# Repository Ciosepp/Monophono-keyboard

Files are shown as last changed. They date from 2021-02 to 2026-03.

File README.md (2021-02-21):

Mono Keyboard Analog Controller features

1-Monophonic pitch CV control
2-Gate CV control
3-Pitch bend wheel CV
4-Mod/expression wheel
5-Mod cv source selection
6-Two auxiliary CV controls
7-Midi out
8-Arpeggiator hold function
9-Arpeggiator latch function 
10-Arpeggiator time setting {60-300bpm}
11-Arpeggiator mode setting {up-down-up/down}
12-Arpeggiator ck source selection {int/ext}
13-Arpeggiator octave extension setting {1-2-3}Monophono-keyboard

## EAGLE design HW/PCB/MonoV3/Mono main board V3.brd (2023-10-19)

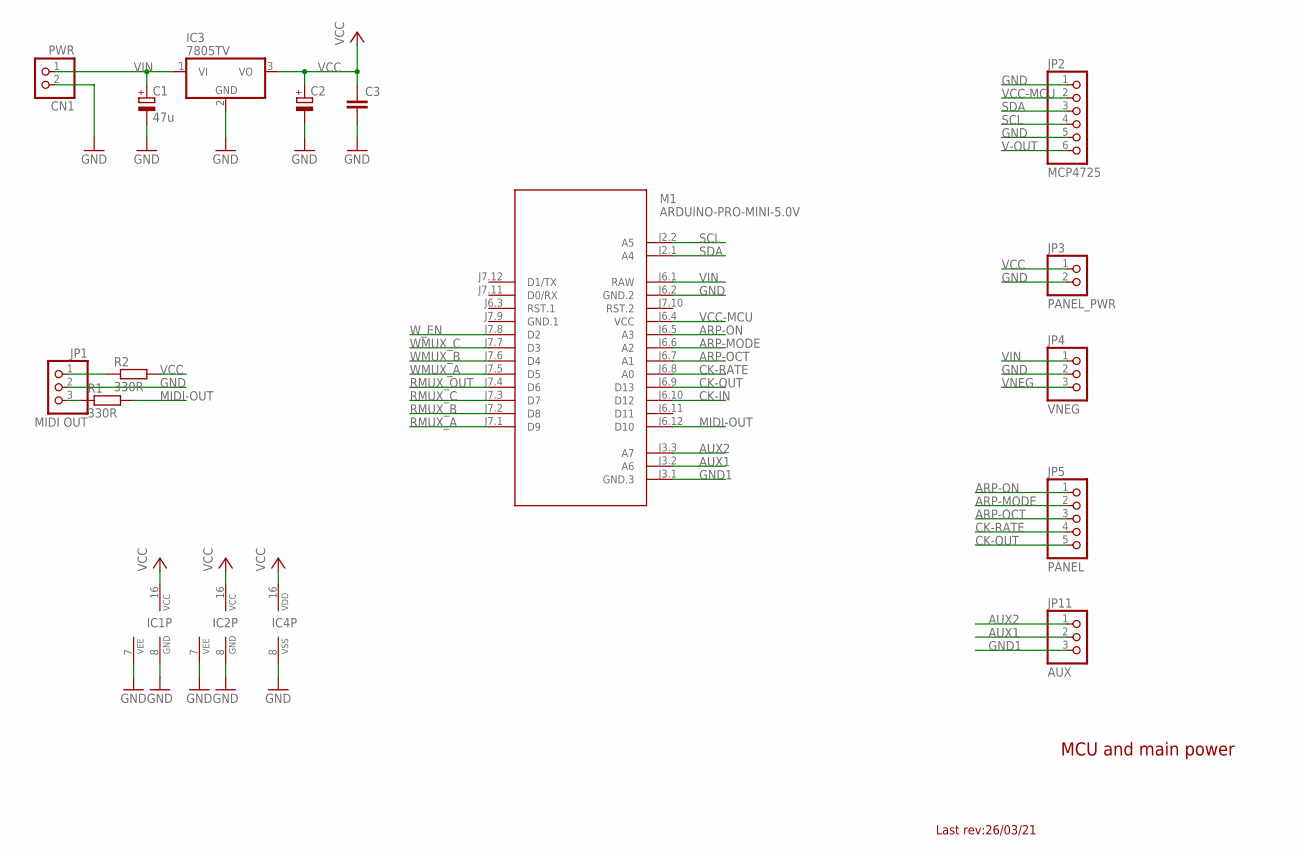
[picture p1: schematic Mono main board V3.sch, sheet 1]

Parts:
C1: 47u; E5-8,5
C2: CPOL-EUE5-8.5; E5-8,5
C3: C-EU050-025X075; C050-025X075
CN1: PWR; JST-PH-2-THM
IC1, IC2: 4051D; SO16
IC3: 7805TV; TO220V
IC4: 4040N; DIL16
JP1: MIDI OUT; 1X03
JP2: MCP4725; 1X06-CLEANBIG
JP3: PANEL_PWR; 1X02
JP4: VNEG; 1X03
JP5: PANEL; 1X05
JP11: AUX; 1X03
M1: ARDUINO-PRO-MINI-5.0V; ARDUINO-PRO-MINI#NP
R1, R2: 330R; R0805

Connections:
ARP-MODE: JP5.2, M1.J6.6 (A2)
ARP-OCT: JP5.3, M1.J6.7 (A1)
ARP-ON: JP5.1, M1.J6.5 (A3)
AUX1: JP11.2, M1.J3.2 (A6)
AUX2: JP11.1, M1.J3.3 (A7)
CK-IN: M1.J6.10 (D12); also elsewhere on the board
CK-OUT: JP5.5, M1.J6.9 (D13)
CK-RATE: JP5.4, M1.J6.8 (A0)
GND: C1.-, C2.-, C3.2, CN1.2 (1), IC1.7 (VEE), IC1.8 (GND), IC2.7 (VEE), IC2.8 (GND), IC3.2 (GND), IC4.8 (VSS), JP1.2, JP2.1, JP2.5, JP3.2, JP4.2, M1.J6.2 (GND.2); also elsewhere on the board
GND1: JP11.3, M1.J3.1 (GND.3)
GND.1: M1.J7.9 (GND.1)
MIDI-OUT: M1.J6.12 (D10), R1.2
unnamed: JP1.1, R2.1
unnamed: JP1.3, R1.1
RMUX_A: M1.J7.1 (D9); also elsewhere on the board
RMUX_B: M1.J7.2 (D8); also elsewhere on the board
RMUX_C: M1.J7.3 (D7); also elsewhere on the board
RMUX_OUT: M1.J7.4 (D6); also elsewhere on the board
SCL: JP2.4, M1.J2.2 (A5)
SDA: JP2.3, M1.J2.1 (A4)
V-OUT: JP2.6; also elsewhere on the board
VCC: C2.+, C3.1, IC1.16 (VCC), IC2.16 (VCC), IC3.3 (VO), IC4.16 (VDD), JP3.1, R2.2; also elsewhere on the board
VCC-MCU: JP2.2, M1.J6.4 (VCC)
VIN: C1.+, CN1.1 (2), IC3.1 (VI), JP4.1, M1.J6.1 (RAW); also elsewhere on the board
VNEG: JP4.3; also elsewhere on the board
WMUX_A: M1.J7.5 (D5); also elsewhere on the board
WMUX_B: M1.J7.6 (D4); also elsewhere on the board
WMUX_C: M1.J7.7 (D3); also elsewhere on the board
W_EN: M1.J7.8 (D2); also elsewhere on the board

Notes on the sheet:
MCU and main power
Last rev:26/03/21

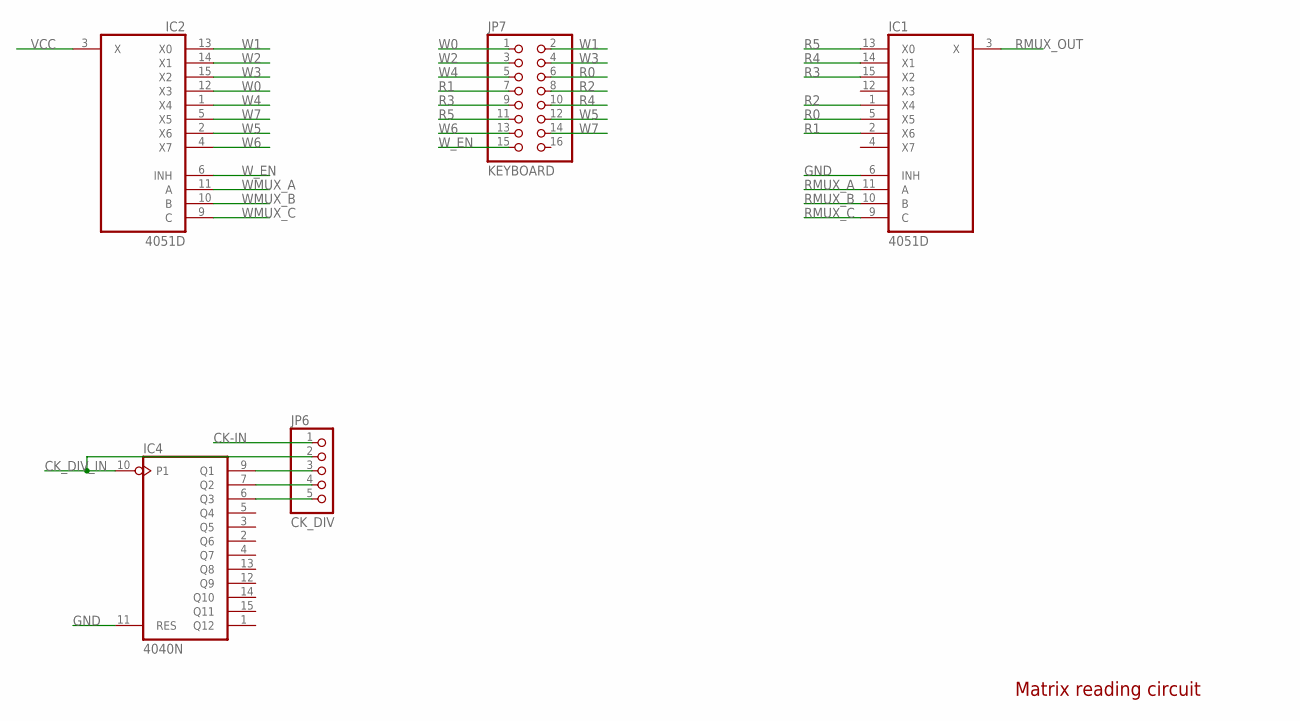
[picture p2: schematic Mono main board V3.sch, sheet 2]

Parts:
IC1, IC2: 4051D; SO16
IC4: 4040N; DIL16
JP6: CK_DIV; 1X05
JP7: KEYBOARD; 2X08

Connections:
CK-IN: JP6.1; also elsewhere on the board
CK_DIV_IN: IC4.10 (P1), JP6.2
GND: IC1.6 (INH), IC4.11 (RES); also elsewhere on the board
unnamed: IC4.9 (Q1), JP6.3
unnamed: IC4.7 (Q2), JP6.4
unnamed: IC4.6 (Q3), JP6.5
R0: IC1.5 (X5), JP7.6
R1: IC1.2 (X6), JP7.7
R2: IC1.1 (X4), JP7.8
R3: IC1.15 (X2), JP7.9
R4: IC1.14 (X1), JP7.10
R5: IC1.13 (X0), JP7.11
RMUX_A: IC1.11 (A); also elsewhere on the board
RMUX_B: IC1.10 (B); also elsewhere on the board
RMUX_C: IC1.9 (C); also elsewhere on the board
RMUX_OUT: IC1.3 (X); also elsewhere on the board
VCC: IC2.3 (X); also elsewhere on the board
W0: IC2.12 (X3), JP7.1
W1: IC2.13 (X0), JP7.2
W2: IC2.14 (X1), JP7.3
W3: IC2.15 (X2), JP7.4
W4: IC2.1 (X4), JP7.5
W5: IC2.2 (X6), JP7.12
W6: IC2.4 (X7), JP7.13
W7: IC2.5 (X5), JP7.14
WMUX_A: IC2.11 (A); also elsewhere on the board
WMUX_B: IC2.10 (B); also elsewhere on the board
WMUX_C: IC2.9 (C); also elsewhere on the board
W_EN: IC2.6 (INH), JP7.15; also elsewhere on the board

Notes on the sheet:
Matrix reading circuit

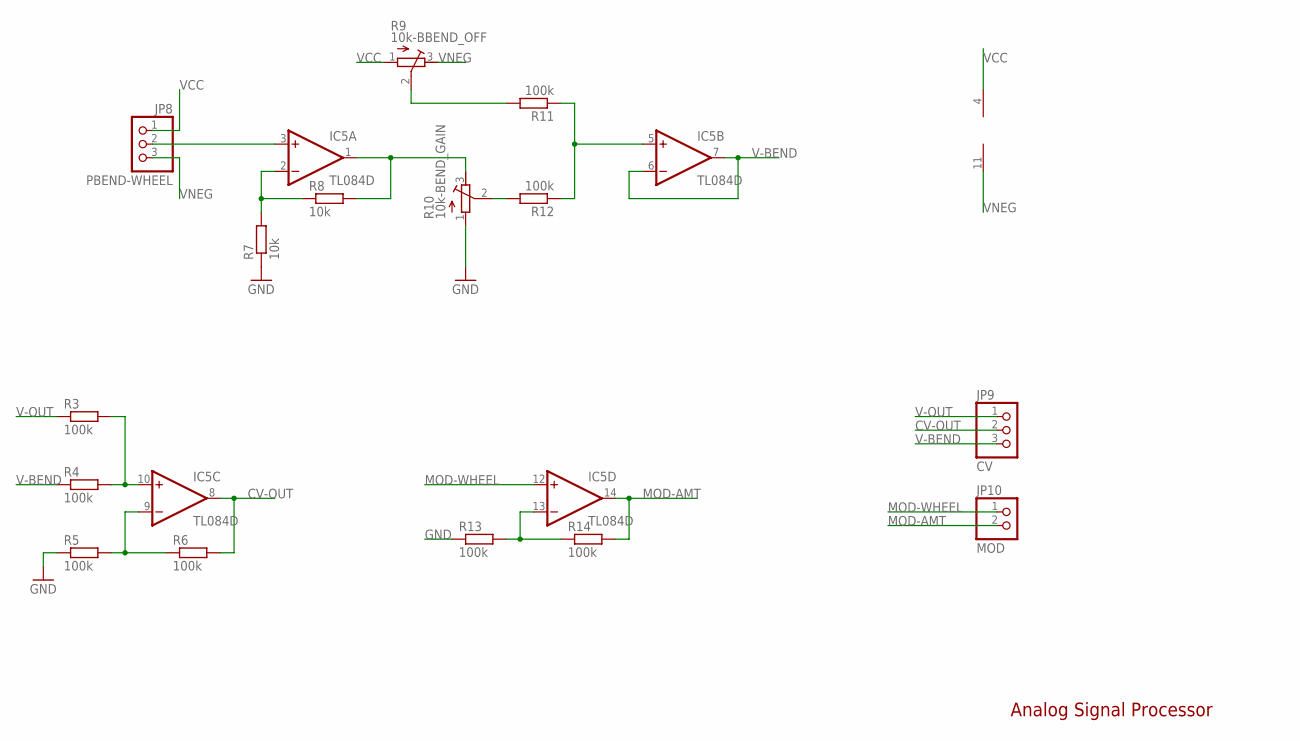
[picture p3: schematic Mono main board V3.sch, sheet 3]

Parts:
IC5: TL084D; SO14
JP8: PBEND-WHEEL; 1X03
JP9: CV; 1X03
JP10: MOD; 1X02
R3, R4, R5, R6, R11, R12, R13, R14: 100k; R0805
R7, R8: 10k; R0805
R9: 10k-BBEND_OFF; RTRIM64W
R10: 10k-BEND_GAIN; RTRIM64W

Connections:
CV-OUT: IC5.8 (OUT), JP9.2, R6.2
GND: R5.1, R7.1, R10.1 (A), R13.1; also elsewhere on the board
MOD-AMT: IC5.14 (OUT), JP10.2, R14.2
MOD-WHEEL: IC5.12 (+IN), JP10.1
unnamed: IC5.10 (+IN), R3.2, R4.2
unnamed: IC5.9 (-IN), R5.2, R6.1
unnamed: IC5.3 (+IN), JP8.2
unnamed: IC5.2 (-IN), R7.2, R8.1
unnamed: R10.2 (S), R12.2
unnamed: R9.2 (S), R11.2
unnamed: IC5.5 (+IN), R11.1, R12.1
unnamed: IC5.13 (-IN), R13.2, R14.1
unnamed: IC5.1 (OUT), R8.2, R10.3 (E)
V-BEND: IC5.6 (-IN), IC5.7 (OUT), JP9.3, R4.1
V-OUT: JP9.1, R3.1; also elsewhere on the board
VCC: IC5.4 (V+), JP8.1, R9.1 (A); also elsewhere on the board
VNEG: IC5.11 (V-), JP8.3, R9.3 (E); also elsewhere on the board

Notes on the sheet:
Analog Signal Processor

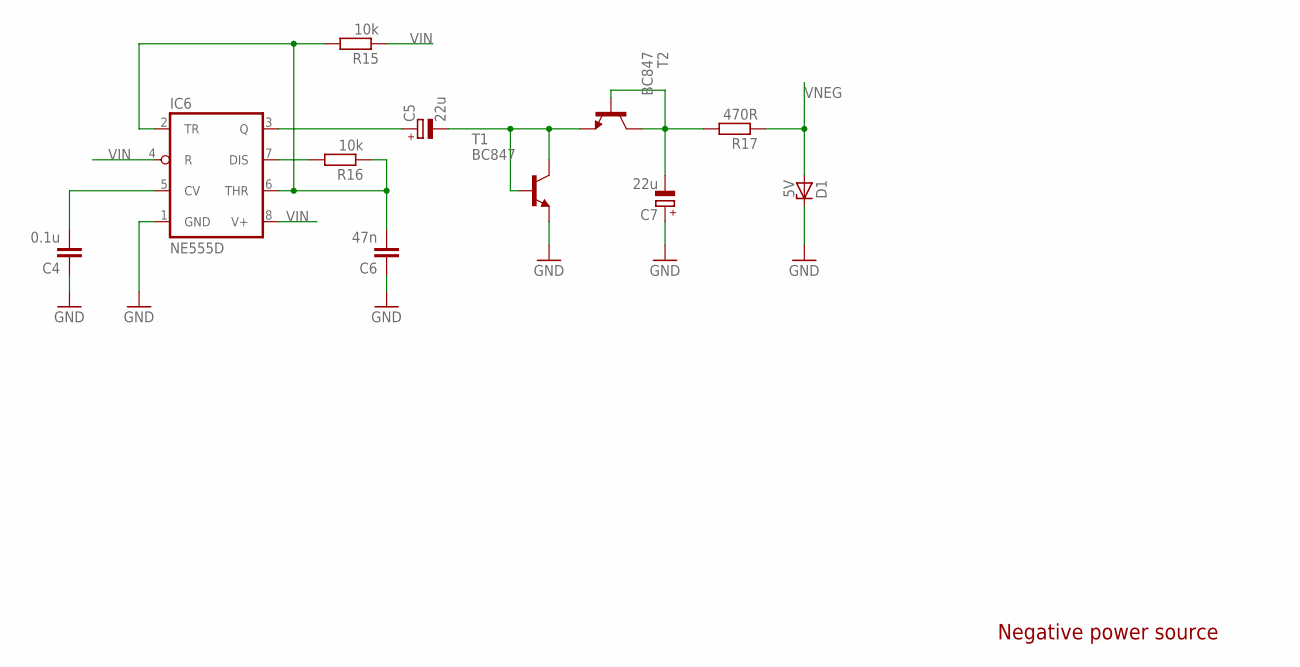
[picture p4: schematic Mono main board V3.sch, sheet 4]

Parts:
C4: 0.1u; C0805
C5, C7: 22u; E5-10,5
C6: 47n; C0805
D1: 5V; ZDIO-2.5
IC6: NE555D; SO08
R15, R16: 10k; M0805
R17: 470R; M0805
T1, T2: BC847; SOT23

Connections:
GND: C4.1, C6.1, C7.+, D1.C, IC6.1 (GND), T1.2 (E); also elsewhere on the board
unnamed: C4.2, IC6.5 (CV)
unnamed: C6.2, IC6.2 (TR), IC6.6 (THR), R15.2, R16.1
unnamed: IC6.7 (DIS), R16.2
unnamed: C5.+, IC6.3 (Q)
unnamed: C7.-, R17.2, T2.1 (B), T2.3 (C)
unnamed: C5.-, T1.1 (B), T1.3 (C), T2.2 (E)
VIN: IC6.4 (R), IC6.8 (V+), R15.1; also elsewhere on the board
VNEG: D1.A, R17.1; also elsewhere on the board

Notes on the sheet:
Negative power source

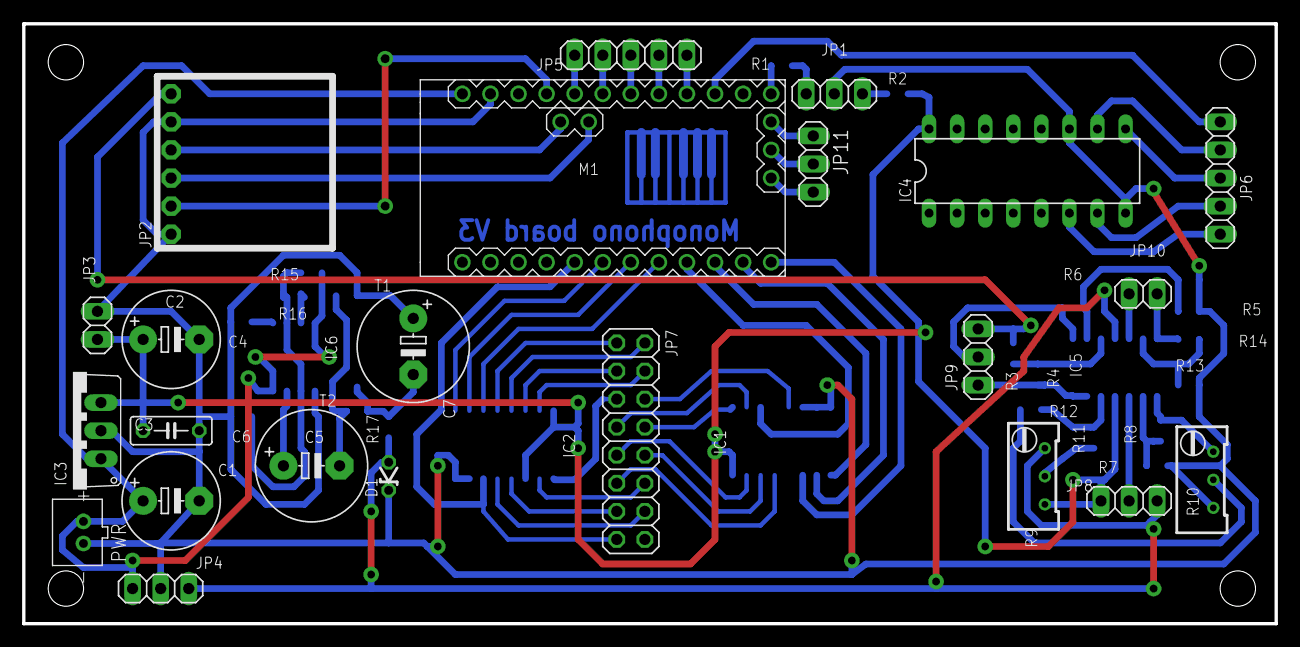
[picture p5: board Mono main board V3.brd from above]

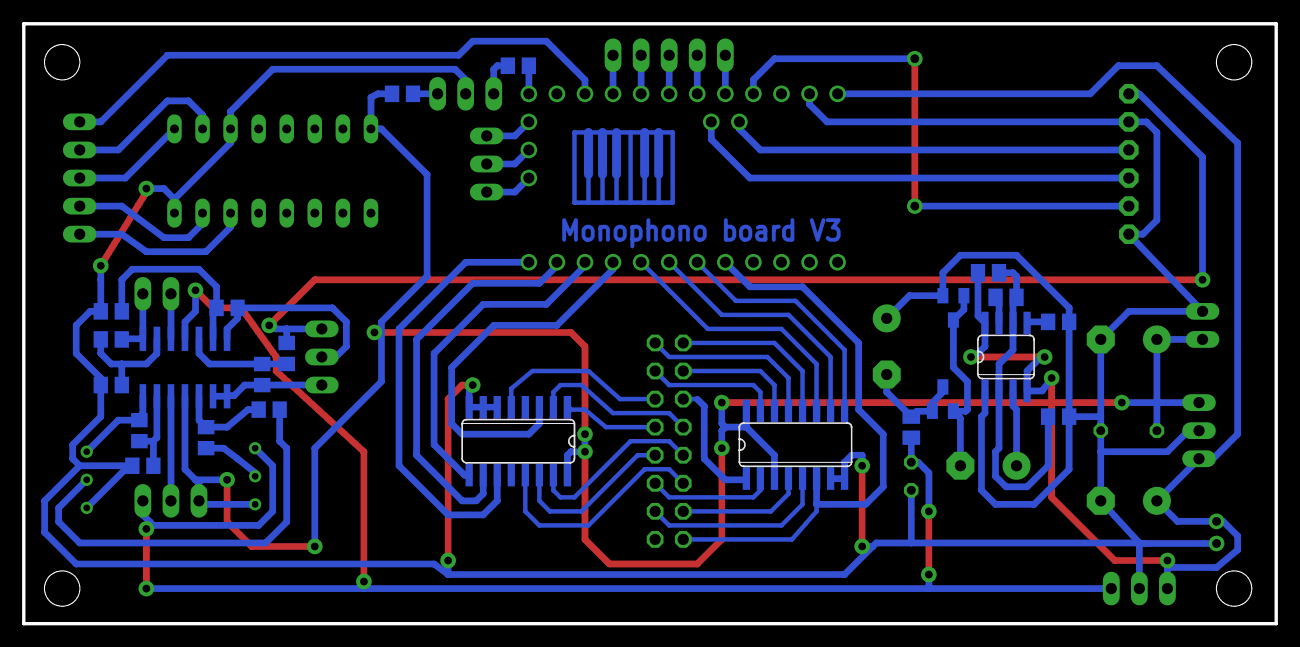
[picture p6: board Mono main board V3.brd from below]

Board: 2 copper layers, 113.3 x 54.3 mm, 46 parts (23 on the bottom side), 65 nets.

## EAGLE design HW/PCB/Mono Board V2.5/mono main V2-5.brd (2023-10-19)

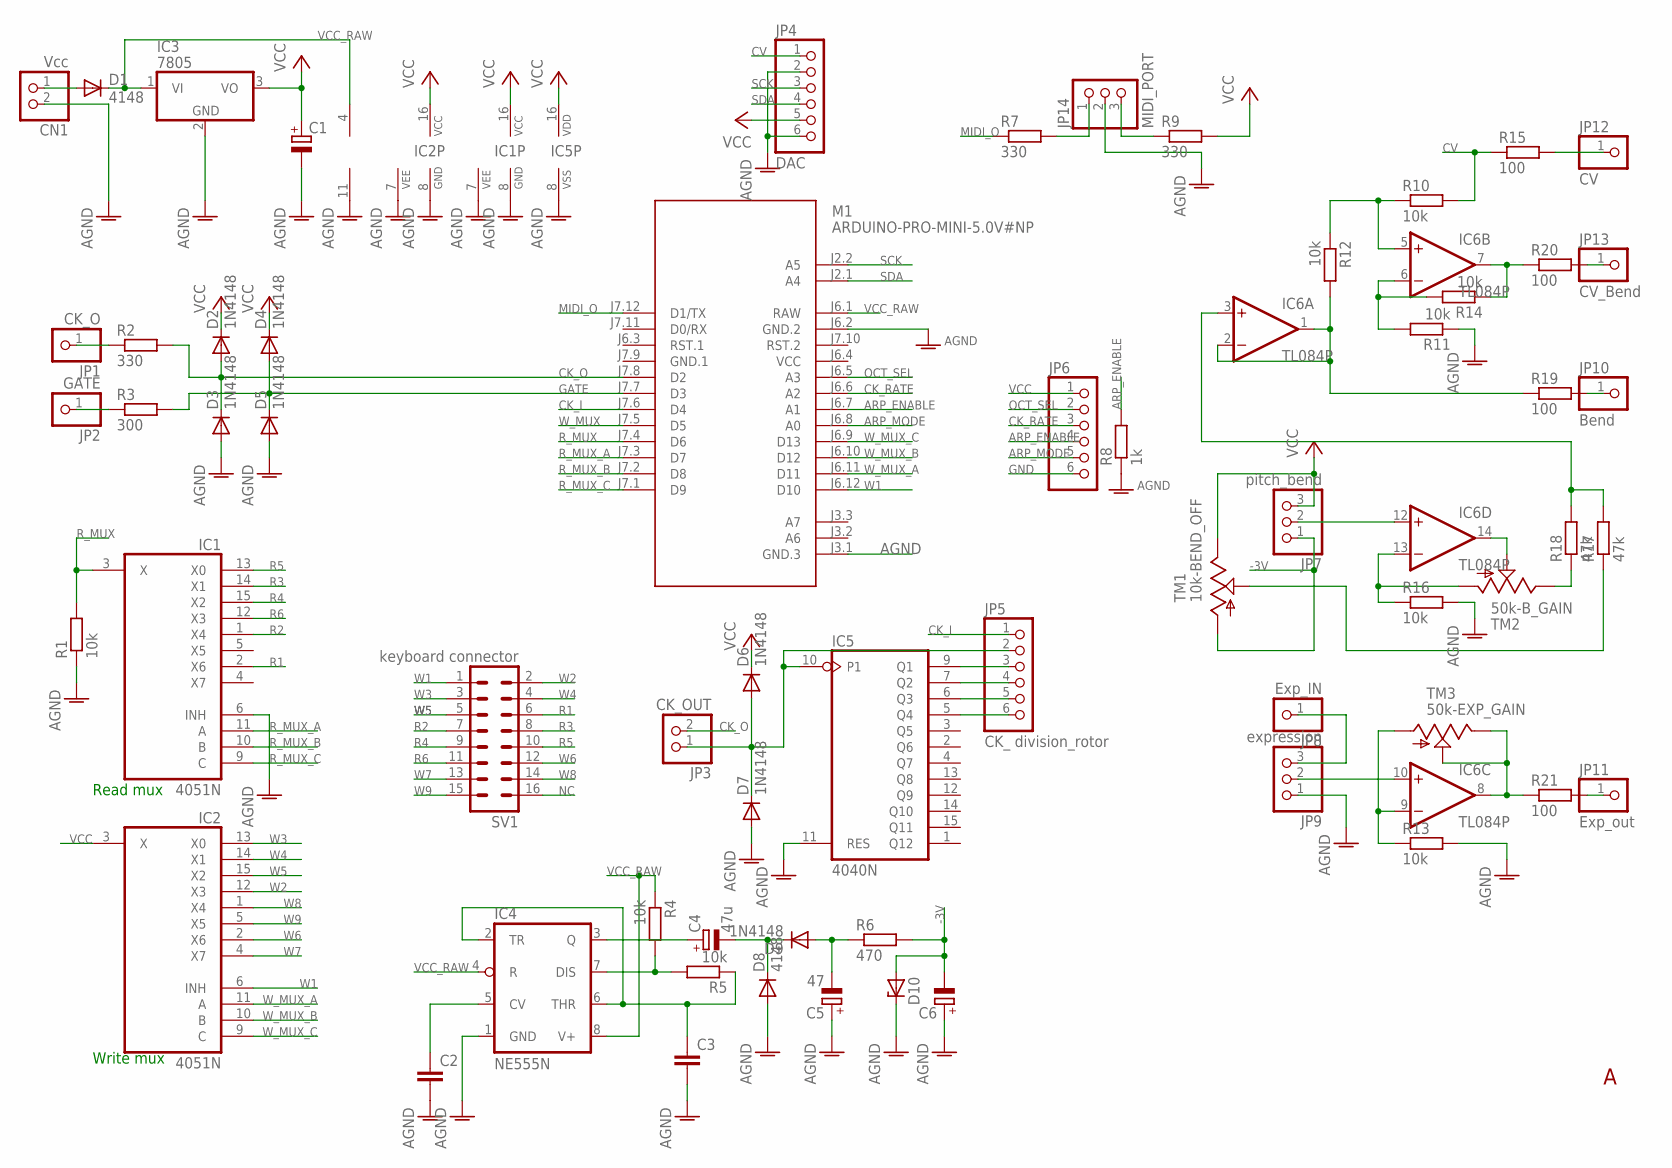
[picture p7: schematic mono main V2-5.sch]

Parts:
C1, C6: CPOL-EUE5-8.5; E5-8,5
C2, C3: C-EU050-030X075; C050-030X075
C4: 47u; E5-8,5
C5: 47; E5-8,5
CN1: Vcc; JST-PH-2-THM
D1, D8: 4148; D-2.5
D2, D3, D6, D7, D9: 1N4148; D-2.5
D4, D5: 1N4148; DO35-7
D10: ZENER-DIODEZD-7.5; ZDIO-7.5
IC1, IC2: 4051N; DIL16
IC3: 7805; TO220V
IC4: NE555N; DIL08-ROUND
IC5: 4040N; DIL16
IC6: TL084P; DIL14
JP1: CK_O; 1X01
JP2: GATE; 1X01
JP3: CK_OUT; 1X02
JP4: DAC; 1X06
JP5: CK_ division_rotor; 1X06
JP6: PINHD-1X6; 1X06
JP7: pitch_bend; 1X03
JP8: Exp_IN; 1X01
JP9: expression; 1X03
JP10: Bend; 1X01
JP11: Exp_out; 1X01
JP12: CV; 1X01
JP13: CV_Bend; 1X01
JP14: MIDI_PORT; 1X03
M1: ARDUINO-PRO-MINI-5.0V#NP; ARDUINO-PRO-MINI#NP
R1, R12: 10k; 0204/7
R2, R7, R9: 330; 0204V
R3: 300; 0204V
R4, R5, R10, R11, R13, R14, R16: 10k; 0204V
R6: 470; 0204V
R8: 1k; 0204/7
R15, R19, R20, R21: 100; 0204V
R17: 47k; 0204V
R18: 47k; 0204/7
SV1: keyboard connector; MA08-2
TM1: 10k-BEND_OFF; 6MM
TM2: 50k-B_GAIN; 6MM
TM3: 50k-EXP_GAIN; 6MM

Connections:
-3V: C6.-, D10.A, JP7.1, R6.2, TM1.A
AGND: C1.-, C2.2, C3.2, C5.+, C6.+, CN1.2 (1), D3.A, D5.A, D7.A, D8.A, D10.C, IC1.6 (INH), IC1.7 (VEE), IC1.8 (GND), IC2.7 (VEE), IC2.8 (GND), IC3.2 (GND), IC4.1 (GND), IC5.8 (VSS), IC5.11 (RES), IC6.11 (V-), JP4.2, JP4.6, JP9.1, JP14.2, M1.J3.1 (GND.3), M1.J6.2 (GND.2), R1.1, R8.1, R11.1, R13.2, R16.2
ARP_ENABLE: JP6.4, M1.J6.7 (A1), R8.2
ARP_MODE: JP6.5, M1.J6.8 (A0)
CK_I: JP5.1, M1.J7.6 (D4)
CK_O: D2.A, D3.C, JP3.2, M1.J7.8 (D2), R2.2
CK_RATE: JP6.3, M1.J6.6 (A2)
CV: JP4.1, R10.2, R15.1
GATE: D4.A, D5.C, M1.J7.7 (D3), R3.2
GND: JP6.6
GND.1: M1.J7.9 (GND.1)
MIDI_O: M1.J7.12 (D1/TX), R7.1
unnamed: IC6.14 (OUT), TM2.S
unnamed: R17.1, TM1.S
unnamed: R18.1, TM2.E
unnamed: IC6.3 (+IN), R17.2, R18.2
unnamed: IC6.1 (OUT), IC6.2 (-IN), R12.2, R19.1
unnamed: JP10.1, R19.2
unnamed: JP13.1, R20.2
unnamed: JP11.1, R21.2
unnamed: JP12.1, R15.2
unnamed: JP1.1, R2.1
unnamed: IC5.9 (Q1), JP5.3
unnamed: IC5.7 (Q2), JP5.4
unnamed: IC5.6 (Q3), JP5.5
unnamed: IC5.5 (Q4), JP5.6
unnamed: D6.A, D7.C, IC5.10 (P1), JP3.1, JP5.2
unnamed: JP2.1, R3.1
unnamed: JP14.1, R7.2
unnamed: JP14.3, R9.1
unnamed: IC6.9 (-IN), R13.1, TM3.A
unnamed: IC4.7 (DIS), R4.2, R5.2
unnamed: C3.1, IC4.2 (TR), IC4.6 (THR), R5.1
unnamed: C2.1, IC4.5 (CV)
unnamed: C4.+, IC4.3 (Q)
unnamed: C4.-, D8.C, D9.C
unnamed: C5.-, D9.A, R6.1
unnamed: IC6.12 (+IN), JP7.2
unnamed: IC6.13 (-IN), R16.1, TM2.A
unnamed: IC6.10 (+IN), JP9.2
unnamed: IC6.8 (OUT), R21.1, TM3.E, TM3.S
unnamed: CN1.1 (2), D1.A
unnamed: IC6.6 (-IN), R11.2, R14.2
unnamed: IC6.7 (OUT), R14.1, R20.1
unnamed: IC6.5 (+IN), R10.1, R12.1
unnamed: JP8.1, JP9.3
NC: SV1.16
OCT_SEL: JP6.2, M1.J6.5 (A3)
R1: IC1.2 (X6), SV1.6
R2: IC1.1 (X4), SV1.7
R3: IC1.14 (X1), SV1.8
R4: IC1.15 (X2), SV1.9
R5: IC1.13 (X0), SV1.10
R6: IC1.12 (X3), SV1.11
R_MUX: IC1.3 (X), M1.J7.4 (D6), R1.2
R_MUX_A: IC1.11 (A), M1.J7.3 (D7)
R_MUX_B: IC1.10 (B), M1.J7.2 (D8)
R_MUX_C: IC1.9 (C), M1.J7.1 (D9)
SCK: JP4.3, M1.J2.2 (A5)
SDA: JP4.4, M1.J2.1 (A4)
VCC: C1.+, D2.C, D4.C, D6.C, IC1.16 (VCC), IC2.3 (X), IC2.16 (VCC), IC3.3 (VO), IC5.16 (VDD), JP4.5, JP6.1, JP7.3, M1.J6.4 (VCC), R9.2, TM1.E
VCC_RAW: D1.C, IC3.1 (VI), IC4.4 (R), IC4.8 (V+), IC6.4 (V+), M1.J6.1 (RAW), R4.1
W1: IC2.6 (INH), M1.J6.12 (D10), SV1.1
W2: IC2.12 (X3), SV1.2
W3: IC2.13 (X0), SV1.3
W4: IC2.14 (X1), SV1.4
W5: IC2.15 (X2), SV1.5
W6: IC2.2 (X6), SV1.12
W7: IC2.4 (X7), SV1.13
W8: IC2.1 (X4), SV1.14
W9: IC2.5 (X5), SV1.15
W_MUX: M1.J7.5 (D5)
W_MUX_A: IC2.11 (A), M1.J6.11 (D11)
W_MUX_B: IC2.10 (B), M1.J6.10 (D12)
W_MUX_C: IC2.9 (C), M1.J6.9 (D13)

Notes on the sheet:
Read mux
Write mux

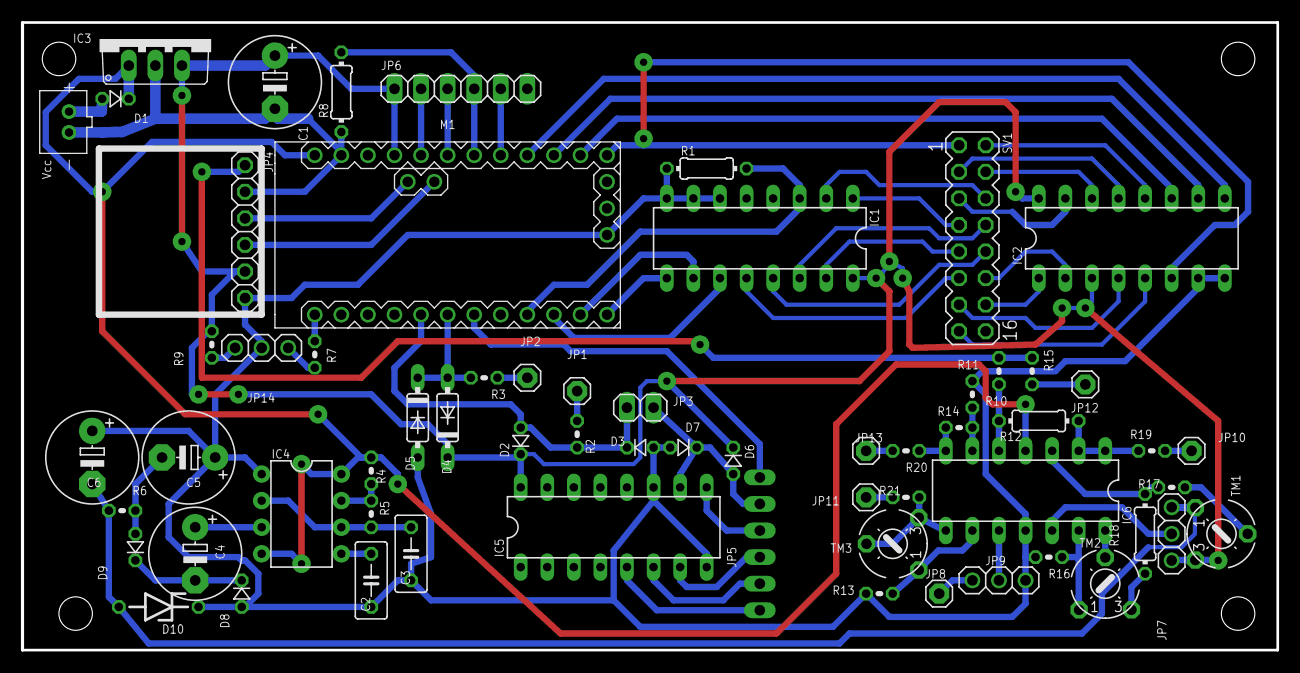
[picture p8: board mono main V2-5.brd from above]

Board: 2 copper layers, 120.0 x 60.0 mm, 63 parts (1 on the bottom side), 71 nets.

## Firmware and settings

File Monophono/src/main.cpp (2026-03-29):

#include <Arduino.h>

#include "config.h"
#include "pin_config.h"
#include "hwFunct.h"
#include "Functions.h"

#include "outputCtrl.h"

bool flag=false;
String str;

void setup() {

	Serial.begin(115200);
	Serial.print("Monophono debug \n");

	Init();

	clockSet(120, 2);

	
}

void loop() {
	
	readInputs();
	
	logic();

	output();
	

	if(!printFlag && CLOCK()) {

		// Serial.print("ARP_OCTAVE: ");
		// Serial.print(ARP_OCTAVE);
		// //Serial.println("");
		// Serial.print("  A_state: ");
		// Serial.print(arpState);
		// //Serial.println("");
		// Serial.print("  A_mode: ");
		// Serial.print(arpMode);
		// Serial.println("");

		// Serial.print("Pressed NOTES:");
		// Serial.println("");
		// for (int i = 0; i < N_KEYS; i++) {
		// Serial.print(KeyStates[i]);
		// }
	// 	Serial.println("");
	// 	Serial.print("ARP NOTES: ");

		// for (int i = 0; i < 21; i++){
		// 	Serial.print(arpeggiatorNotes[i]);
		// 	Serial.print(" ");
		// }	
	// 	Serial.println("");
	// 	Serial.print("current Note: ");
	// 	Serial.print(NOTE);
	// 	Serial.println("");
	// 	Serial.println("");
		printFlag = true;
	 }
	if(printFlag && !CLOCK()) printFlag=false;
	//Serial.println(voltages[NOTE]);
	//Serial.println(nPressedKeys);
}

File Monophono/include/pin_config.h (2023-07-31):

#ifndef PIN_CONFIG_H
#define PIN_CONFIG_H    
//
// define HERE the version of the BOARD
#define version 25
//#define version 3

#if version == 3
	#define __V3_BOARD__
#elif version == 25
	#define __V2_5_BOARD__
#endif
const short N_ROWS = 9;
const short N_COLUMNS = 6;

////				BOARD: V3

#ifdef __V2_5_BOARD__
	#define MIDI_OUT_PIN 1
    #define CLOCK_OUT_PIN 2
    #define GATE_PIN 3

    #define W_MUX_C_PIN     13
    #define W_MUX_B_PIN     12
    #define W_MUX_A_PIN     11
    #define W_EN_PIN        10
    #define R_MUX_OUT_PIN   6
    #define R_MUX_A_PIN     7
    #define R_MUX_B_PIN     8
    #define R_MUX_C_PIN     9
    //#define MATRIX_WRITE_EXTERNAL_PIN 13
    //const short int WRITE_MUX_ADDRESS_PINS[] = {10, 11, 12};
    //#define READ_MUX_OUT_VALUE_PIN 9
    //const short int READ_MUX_ADDRESS_PINS[] = {6, 7, 8};    
    
    #define CK_IN_PIN 4
    #define ARP_MODE_PIN 14
    #define ARP_ON_PIN 15
    #define CK_AMT_PIN 16
    #define ARP_OCT_PIN 17
    #define SEQUENCER_PIN 20



#endif

#ifdef __V3_BOARD__
    #define W_EN_PIN        2
    #define W_MUX_C_PIN     3
    #define W_MUX_B_PIN     4
    #define W_MUX_A_PIN     5
    #define R_MUX_OUT_PIN   6
    #define R_MUX_C_PIN     7
    #define R_MUX_B_PIN     8
    #define R_MUX_A_PIN     9

    #define MIDI_OUT_PIN    10
    #define NC_PIN          11
    #define CK_IN_PIN       12
    #define CK_OUT_PIN      13
    #define CK_AMT_PIN      14
    #define ARP_OCT_PIN     15
    #define ARP_MODE_PIN    16
    #define ARP_ON_PIN      17

    #define I2C_SDA_PIN     18
    #define I2C_SCL_PIN     19
        
    #define AUX1_PIN        20
    #define AUX2_PIN        21
    //hardware port mapping
	//write(rows) multiplexer
    int WRITE_MAP[N_ROWS-1]={3,0,1,2,4,6,7,5};
	//read(colmns) multiplexer
    int READ_MAP[N_COLUMNS]={5,6,4,2,1,0};


#endif

const short WRITE_MUX_ADDRESS_PINS[3] = {
    W_MUX_A_PIN,
    W_MUX_B_PIN,
    W_MUX_C_PIN
};

const short READ_MUX_ADDRESS_PINS[3] = {
    R_MUX_A_PIN,
	R_MUX_B_PIN,
	R_MUX_C_PIN
};


#define PRESSED true
#define N_OCTAVES 4



#endif

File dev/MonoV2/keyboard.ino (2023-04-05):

#include "pin-configuration-board-v2_5.h"
#include "arpeggiator.h"

bool noteDown(int i, bool* noteScan, bool* noteTrans){
    return noteScan[i] && noteTrans[i];
}

bool noteUp(int i, bool* noteScan, bool* noteTrans){
    return noteScan[i] && !noteTrans[i];
}

void gateRefresh(){
    digitalWrite(gatePin, 0);
    digitalWrite(gatePin, 1);
}

void gateOn(){
    digitalWrite(gatePin, 1);
}

void gateOff(){
    digitalWrite(gatePin, 0);
}

void SerialDebug(int N, int* Vector){
    for (int i = 0; i < N; i++){
		Serial.print(Vector[i]);
	}
 	Serial.println("");
}
void PrintKeyScan(){
    for (int i = 0; i < N; i++){
		Serial.print( keyboard[i]);
	}
 	Serial.println("");
}

void pinModeInit(){
	
    for(int i = 0; i < nMuxAddressPins; i++){
        pinMode(ReadMuxAddressPin[i], OUTPUT);
        pinMode(WriteMuxAddressPin[i], OUTPUT);
    }
    pinMode(WriteMuxOutPin, OUTPUT);
    pinMode(ReadMuxInPin, INPUT);
    pinMode(gatePin, OUTPUT);
}

void dacInit(){    //funzione che genera le tensioni specifiche per ogni tasto
	dac.begin(DAC_ADDRES);
	dac.setVoltage(0, false);
	
  	for (uint32_t i = 0; i < 60; i++){
    	voltages[i] = i * 4095 / 60;
  	}  	
}

void muxWrite(int val, int* Pins){
    uint8_t out = val;
    for(int i= 0; i<nMuxAddressPins; i++){

        digitalWrite(Pins[i], out & pow(2,i));    //lsb 0000 0011 & 0000 0001 = 0000 0001 >0 ==> true
    }
    //digitalWrite(Pins[1], out&2);    //    0000 0011 & 0000 0010 = 0000 0010 >0 ==> true
    //digitalWrite(Pins[2], out&4);   //msb 0000 0011 & 0000 0100 = 0000 0000 =0 ==> false
}



void WriteColumn(int index){
    if(index >= 0 && index <=7){
		if (index ==0) {
		    digitalWrite(WRITE_MUX_ENABLE_PIN, 1);
		    digitalWrite(MATRIX_WRITE_EXTERNAL_PIN, 0);
		}
    	muxWrite(WRITE_REROUTING_ARRAY[index], WRITE_MUX_ADDRESS_PINS);
    }else{
    	digitalWrite(WRITE_MUX_ENABLE_PIN, 0);
	    digitalWrite(MATRIX_WRITE_EXTERNAL_PIN, 1);
    }
}



bool readRow(int index){
	muxWrite(READ_REROUTING_ARRAY[index], READ_MUX_ADDRESS_PINS);
	return digitalRead(READ_MUX_OUT_VALUE_PIN);
}

int getOctave(int pin){
    return map(analogRead(pin), 0, 1023, 0, N_ARPEGGIATOR_OCTAVES-1);
}

int getArpeggiatorMode(int pin){
    return map(analogRead(pin), 0, 1023, 0, N_ARPEGGIATOR_MODES-1);
}

int getKeyboardMode(int pin){
    return map(analogRead(pin), 0, 1023, 0, N_KEYBOARD_MODES-1);
}

int getCkRate(){
    return map(analogRead(ARPEGGIATOR_CLOCK_RATE_PIN), 0, 1023, MIN_BPM, MAX_BPM);
}

bool getGate(){
	return digitalRead(ARPEGGIATOR_CLOCK_IN_PIN);
}

void readControls(){
	READ.Gate = getGate();
	READ.Bpm = getCkRate();
	READ.KeyboardMode = getKeyboardMode();
	READ.arpeggiatorMode = getArpeggiatorMode();
	READ.arpeggiatorOctaveExtension = getOctave();

}

int keyboardScan(){

    int columnIndex=0;
    int rowIndex=0;
    int nPressedKeys=0;

    for(int i=0; i<Nkeys; i++){

        columnIndex= i / nColumn;
        rowIndex = i % nRow;

        WriteColumn(columnIndex);
        keyboard[i] = readRow(rowIndex);
        if( keyboard[i])nPressedKeys++;

        transient[i] = oldkeyboard[i] ^ keyboard[i]; //XOR
        oldkeyboard[i] = keyboard[i]; //updating memory vector
    }
    return nPressedKeys;
}

void CvWrite(int note){
	dac.setVoltage(voltages[note], false);
}
void monophonicControl(){
	
	int nPressedKeys = 0;

  	for(int i = 0; i < N; i++){

       	if (noteDown(i, keyboard, transient)){  //detect note down
       		noteOut = i;
       		CvWrite(i);
       		gateRefresh();
            nPressedKeys++;
       		break;
       	}

       	if (noteUp(i, keyboard, transient)){ //detect note release
      		
            nPressedKeys--;
			if (nPressedKeys==0){  //only pressed key release handler
			    gateOff();
			}else{    //release handler selects the first secondly pressed key 
			    noteOut = i;
			    CvWrite(i);
			    gateRefresh();
			}
			
			break;
       	}
    }
  	
}


int noteIndex=0;
void arpeggiator(int* notes, int nNotes, int octaveExtension, int mode){

	if (getGate() && aLatch && nNotes > 0){

		CvWrite(notes[noteIndex]);
       	gateRefresh();
       	aLatch = false;
	}

	if (!getGate() && !aLatch){ 
		switch(mode){
			case 0:	//up mode 
                noteIndex = (noteIndex + 1) % maxArpVoices;
                break;
            case 1:  // up/down mode
                if (noteIndex >= maxArpVoices - 1 && up) up = false; //up
                if (noteIndex <= 0 && !up) up = true;
                if (up) noteIndex++;
                else    
                    noteIndex--;
                break;
            case 2: // down mode
                noteIndex = (noteIndex - 1) % maxArpVoices;
                break;
		}
        aLatch = true;
	}
}

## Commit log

2021-02-19 Code style refactored
    Fixed coding style according to conventions, mainly spacing and indenting.
    No code changes.
    [MonoV2.ino]
2021-02-21 Rework w OoGo
    lol
    [Functions.cpp, MonoV2.ino, hwFunct.cpp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]
2023-04-15 aiuto di alice pt1
2023-04-21 FIRST UPLOAD ON BOARD
2023-10-15 Started implementation of the arpeggiator
    also:
    Added lib cppQueue
    Refactored and corrected code for clock reading
    [Functions.cpp, arpeggiator.cpp, hwFunct.cpp]
2023-10-19 Added PCB files
    [Mono main board V3.brd, Mono main board V3.sch, mono main V2-5.brd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]

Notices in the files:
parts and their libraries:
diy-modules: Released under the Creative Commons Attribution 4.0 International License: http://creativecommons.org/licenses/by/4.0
